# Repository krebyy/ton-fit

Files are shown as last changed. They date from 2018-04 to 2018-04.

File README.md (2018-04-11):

Ton-Fit V2.0
========

The Ton-Fit V2.0 Board is a development and prototyping platform based on the ARM Cortex-M4 32-bit microcontroller [STM32F405](http://www.st.com/en/microcontrollers/stm32f405rg.html).

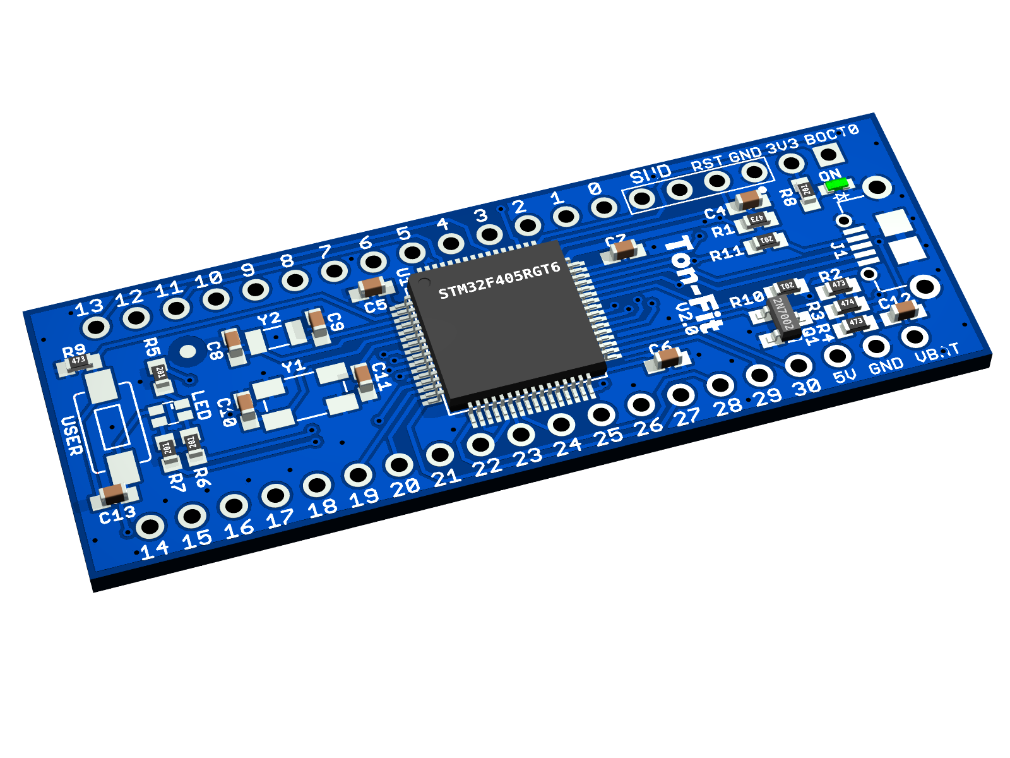
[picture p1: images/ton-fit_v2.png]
ton-fit_v2


# License

Copyright Kleber Lima da Silva 2018.

This documentation describes Open Hardware and is licensed under the CERN OHL v. 1.2.
You may redistribute and modify this documentation under the terms of the CERN OHL v.1.2. (http://ohwr.org/cernohl). This documentation is distributed WITHOUT ANY EXPRESS OR IMPLIED WARRANTY, INCLUDING OF MERCHANTABILITY, SATISFACTORY QUALITY AND FITNESS FOR A PARTICULAR PURPOSE. Please see the CERN OHL v.1.2 for applicable conditions.

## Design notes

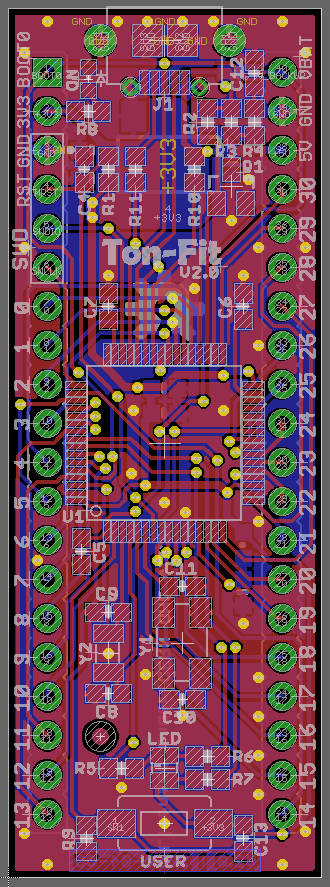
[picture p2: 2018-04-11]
images/ton-fit_v2_eagle.png

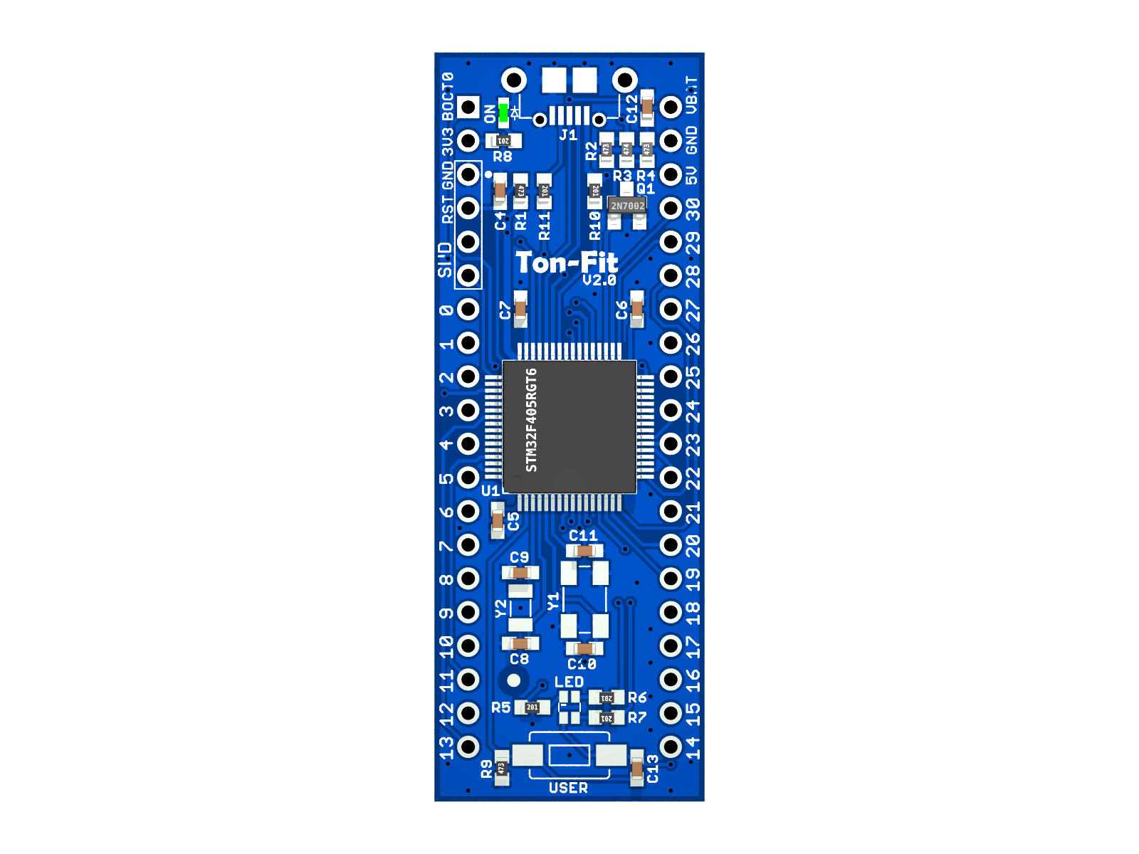
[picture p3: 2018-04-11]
images/ton-fit_v2_top.png

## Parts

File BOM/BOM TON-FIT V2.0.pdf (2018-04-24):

Idn | Reference Designator | Item Type | Item Package | Item Desc | Qty | MFG Name | MFG P/N | Notes
1 | C1, C14, C15 | CERAMIC-CAP | 0603 | CAP CER 1UF 6.3V X5R 0603 10% | 3 | YAGEO | CC0603KRX5R5BB105
2 | C2, C3, C4, C5, C13, C16 | CERAMIC-CAP | 0603 | CAP CER 0.1UF 16V X7R 0603 10% | 6 | YAGEO | CC0603KRX7R7BB104
3 | C6, C7, C12 | CERAMIC-CAP | 0603 | CAP CER 2.2UF 6.3V X5R 0603 10% | 3 | YAGEO | CC0603KRX5R5BB225
4 | C8, C9, C10, C11 | CERAMIC-CAP | 0603 | CAP CER 8.2PF 50V NP0 0603 | 4 | YAGEO | CC0603DRNPO9BN8R2
5 | J1 | USB-CONN | SMD-5 | CONNECTOR USB MICRO AB RECEPTACLE | 1 | MOLEX | 47589-0001
6 | J2 | CONNECTOR | PTH-40 | PIN HEADER 1X40, 2.54MM PITCH | 1 | HARWIN | M20-9994046
7 | L1 | FERRITE-CHIP | 0603 | FERRITE CHIP 120 OHM 500MA 0603 | 1 | TAIYO YUDEN | BK1608HS121-T
8 | LED | LED-RGB | 0606 | LED RGB 0606 | 1 | LITE-ON | LTST-C19HE1WT
9 | ON | LED | 0603 | LED GREEN 0603 | 1 | LITE-ON | LTST-C191KGKT
10 | Q1 | MOSFET | SOT-23-3 | MOSFET 2N7002 N-CHANNEL | 1 | ON SEMICONDUCTOR | 2N7002
11 | R1, R2, R4, R9 | RESISTOR-DISCRETE | 0603 | RES 0603 47K OHM 5% 1/10W | 4 | YAGEO | RC0603JR-0747KL
12 | R3 | RESISTOR-DISCRETE | 0603 | RES 0603 470K OHM 5% 1/10W | 1 | YAGEO | RC0603JR-07470KL
13 | R5, R6, R7, R8, R10, R11 | RESISTOR-DISCRETE | 0603 | RES 0603 200 OHM 5% 1/10W | 6 | YAGEO | RC0603JR-07200RL
14 | R12 | RESISTOR-DISCRETE | 0603 | JUMPER 0603 ZERO OHM | 1 | YAGEO | RC0603JR-070RL | NOT PLACED TO USE EXTERNAL BACKUP BATTERY
15 | U1 | IC | LQFP-64 | IC MCU STM32F405RGT6 | 1 | STMICROELECTRONICS | STM32F405RGT6
16 | U2 | IC | SOT-223-3 | IC LDO VOLTAGE REGULATOR 3.3V | 1 | DIODES INCORPORATED | AZ1117EH-3.3
17 | USER | TACTILE-SWITCH | SMD-4 | TACTILE SWITCH SPST-NO | 1 | TE CONNECTIVITY | FSMSM
18 | Y1 | CRYSTAL | SMD-4 | CRYSTAL ABM3B 8 MHZ | 1 | ABRACON | ABM3B-8.000MHZ-10-1UT
19 | Y2 | CRYSTAL | SMD-2 | CRYSTAL 32.768 KHZ | 1 | ECS | ECS-.327-7-34QCS-TR
Bill of Materials (BOM): TON-FIT V2.0

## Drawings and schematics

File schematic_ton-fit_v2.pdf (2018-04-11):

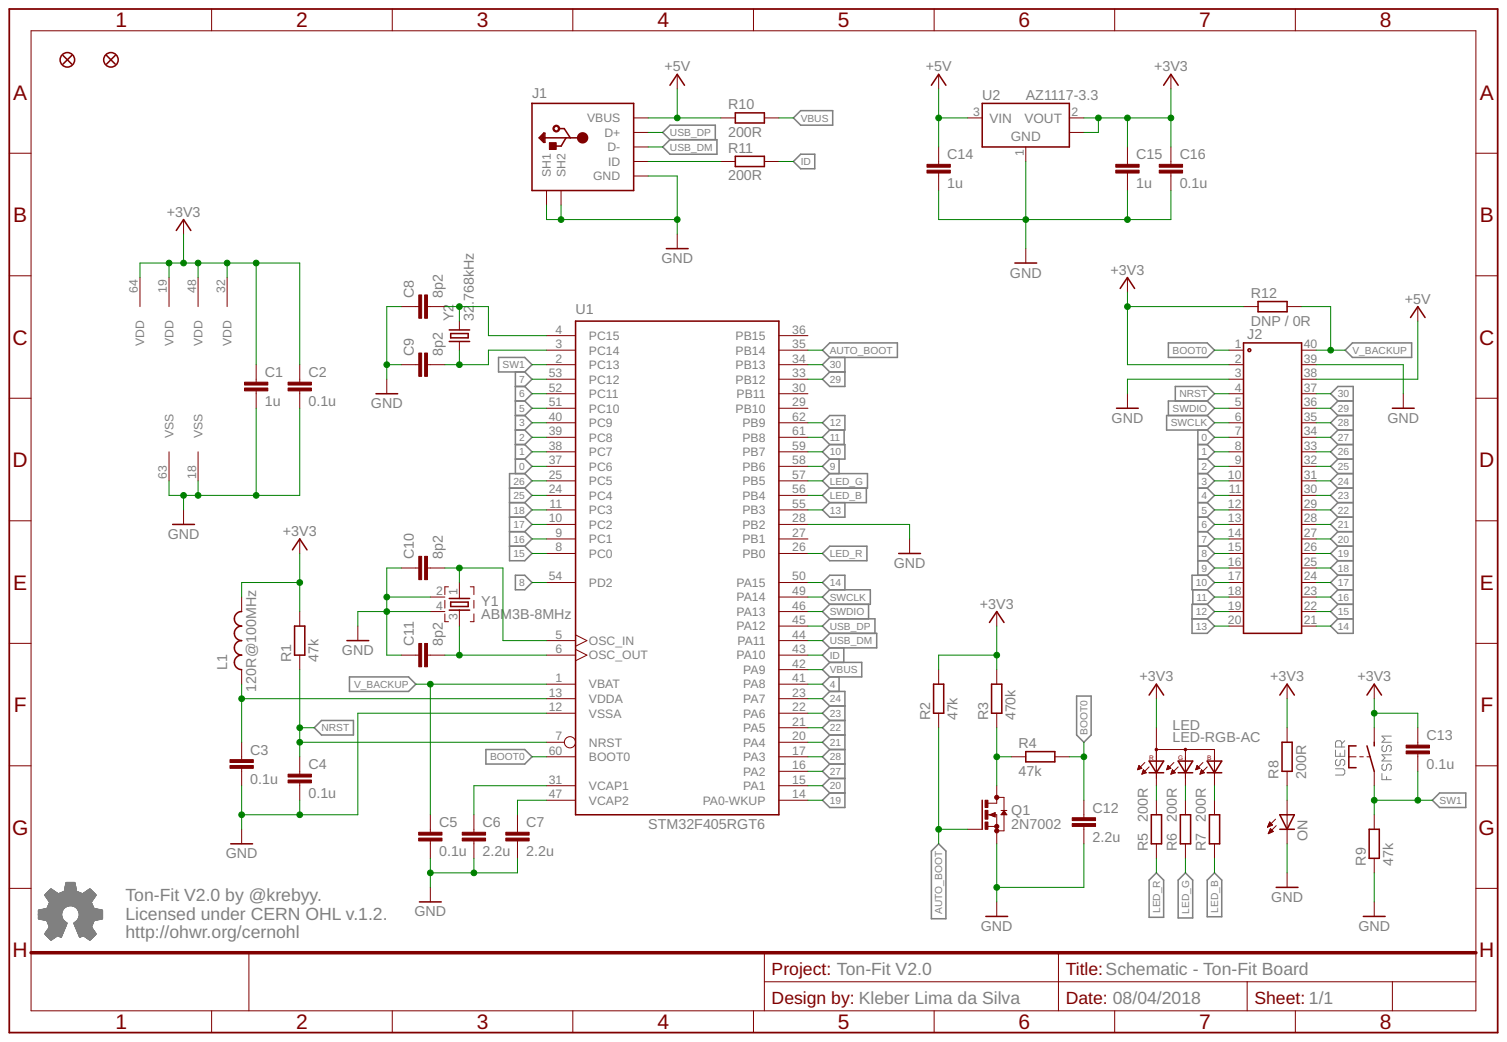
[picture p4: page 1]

Ton-Fit V2.0 by @krebyy. Licensed under CERN OHL v.1.2. http://ohwr.org/cernohl

Project: Ton-Fit V2.0 | Title: Schematic - Ton-Fit Board
Design by: Kleber Lima da Silva | Date: 08/04/2018 | Sheet: 1/1

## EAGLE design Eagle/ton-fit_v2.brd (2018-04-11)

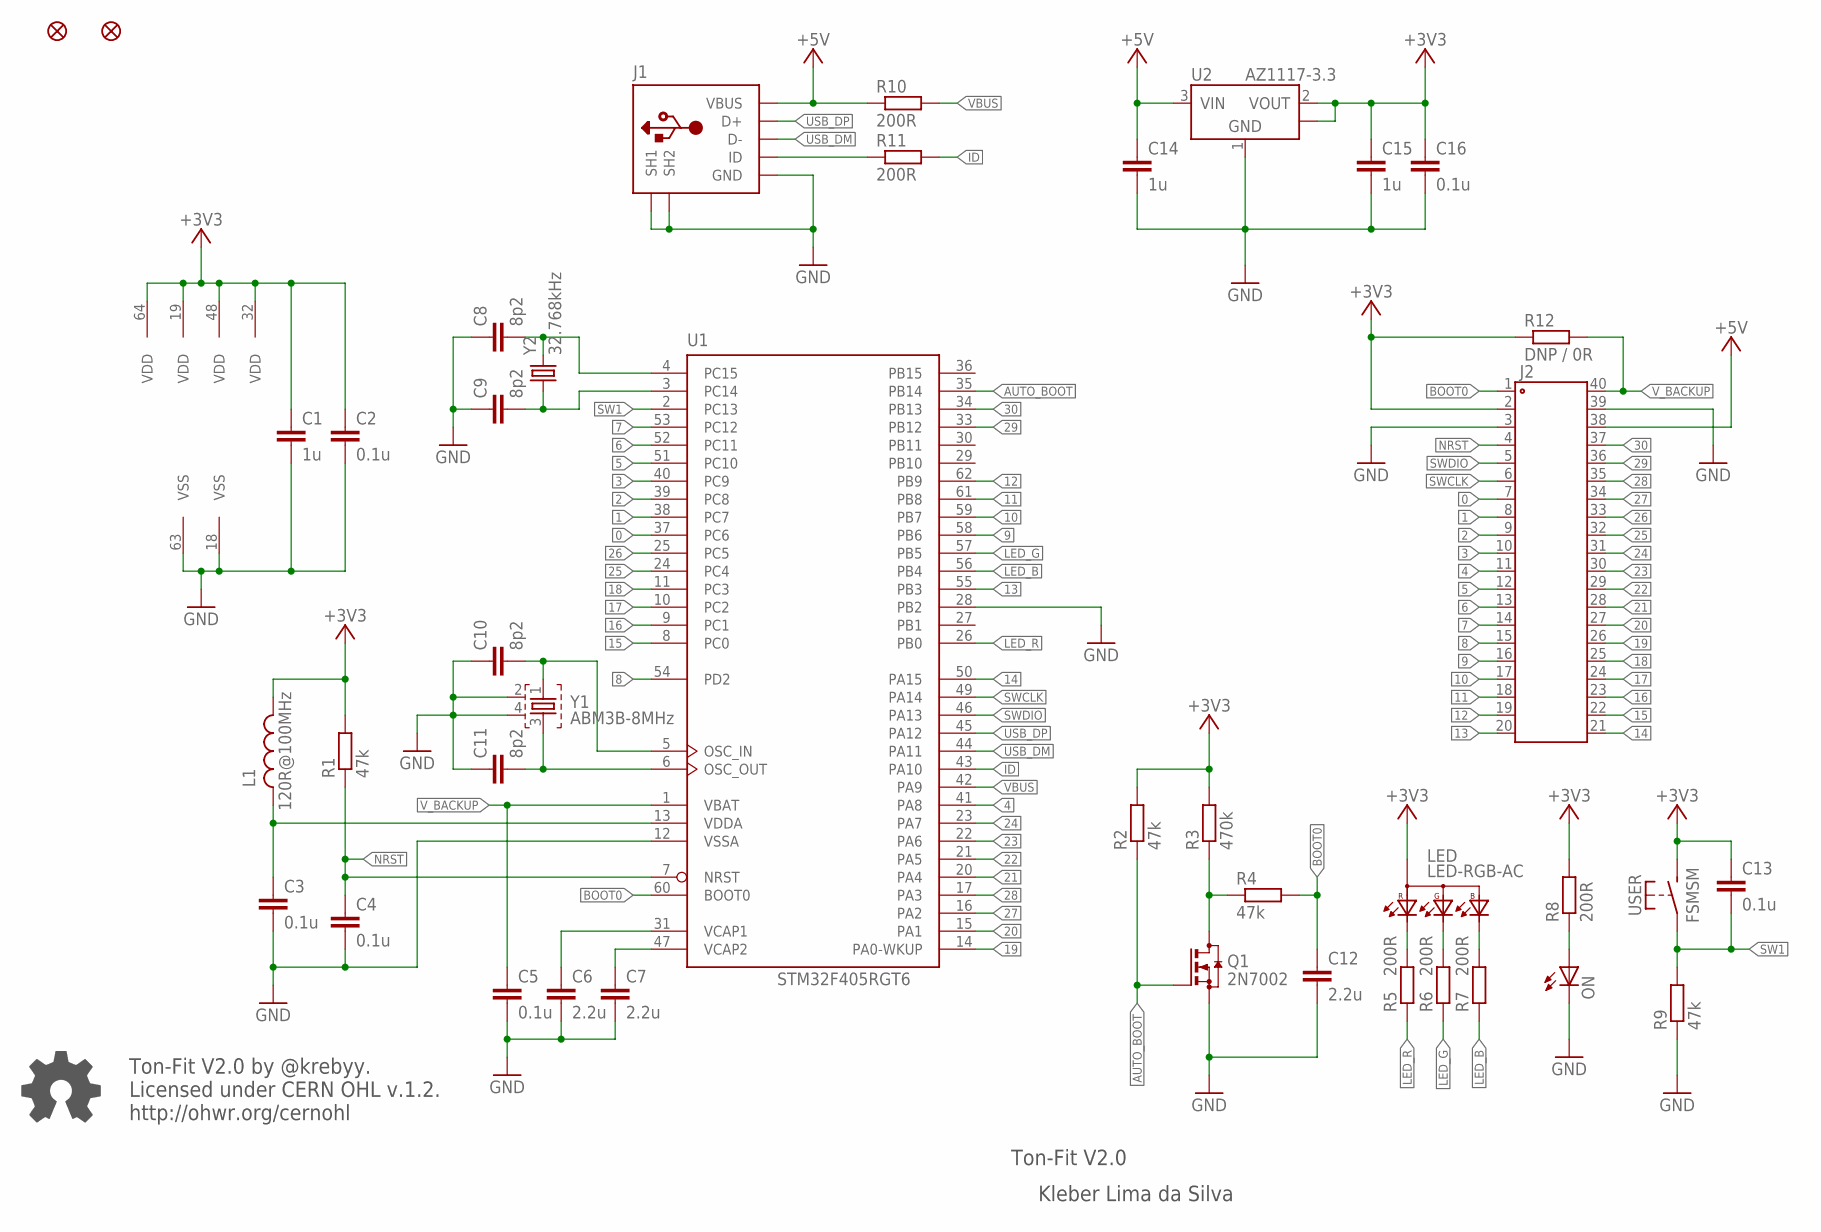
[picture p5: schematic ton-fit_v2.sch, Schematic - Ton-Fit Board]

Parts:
C1, C14, C15: 1u; C0603
C2, C3, C4, C5, C13, C16: 0.1u; C0603
C6, C7, C12: 2.2u; C0603
C8, C9, C10, C11: 8p2; C0603
FIDUCIAL1, FIDUCIAL2: FIDUCIAL; FIDUCIAL-1X2
J1: USBR; 0475890001
J2: DIL40
L1: 120R@100MHz; L0603
LED: LED-RGB-AC; 0606
ON: LEDCHIPLED_0603; CHIPLED_0603
Q1: 2N7002; SOT23
R1, R2, R4, R9: 47k; R0603
R3: 470k; R0603
R5, R6, R7, R8, R10, R11: 200R; R0603
R12: DNP / 0R; R0603
U1: STM32F405RGT6; LQFP64
U2: AZ1117-3.3; SOT223
USER: FSMSM
Y1: ABM3B-8MHz; ABM3B
Y2: 32.768kHz; 3.2X1.5

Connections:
0: J2.7, U1.37 (PC6)
1: J2.8, U1.38 (PC7)
2: J2.9, U1.39 (PC8)
3: J2.10, U1.40 (PC9)
4: J2.11, U1.41 (PA8)
5: J2.12, U1.51 (PC10)
6: J2.13, U1.52 (PC11)
7: J2.14, U1.53 (PC12)
8: J2.15, U1.54 (PD2)
9: J2.16, U1.58 (PB6)
10: J2.17, U1.59 (PB7)
11: J2.18, U1.61 (PB8)
12: J2.19, U1.62 (PB9)
13: J2.20, U1.55 (PB3)
14: J2.21, U1.50 (PA15)
15: J2.22, U1.8 (PC0)
16: J2.23, U1.9 (PC1)
17: J2.24, U1.10 (PC2)
18: J2.25, U1.11 (PC3)
19: J2.26, U1.14 (PA0-WKUP)
20: J2.27, U1.15 (PA1)
21: J2.28, U1.20 (PA4)
22: J2.29, U1.21 (PA5)
23: J2.30, U1.22 (PA6)
24: J2.31, U1.23 (PA7)
25: J2.32, U1.24 (PC4)
26: J2.33, U1.25 (PC5)
27: J2.34, U1.16 (PA2)
28: J2.35, U1.17 (PA3)
29: J2.36, U1.33 (PB12)
30: J2.37, U1.34 (PB13)
+3V3: C1.1, C2.1, C13.1, C15.1, C16.1, J2.2, L1.1, LED.4 (A), R1.2, R2.2, R3.2, R8.2, R12.1, U1.19 (VDD), U1.32 (VDD), U1.48 (VDD), U1.64 (VDD), U2.2 (VOUT), U2.4 (TAB), USER.2
+5V: C14.1, J1.1 (VBUS), J2.38, R10.1, U2.3 (VIN)
AUTO_BOOT: Q1.1 (G), R2.1, U1.35 (PB14)
BOOT0: C12.1, J2.1, R4.2, U1.60 (BOOT0)
GND: C1.2, C2.2, C3.2, C4.2, C5.2, C6.2, C7.2, C8.1, C9.1, C10.1, C11.1, C12.2, C14.2, C15.2, C16.2, J1.5 (GND), J1.SH1, J1.SH2 (SH1), J1.SH3 (SH2), J1.SH4 (SH2), J1.SH5 (SH1), J1.SH6 (SH2), J2.3, J2.39, ON.C, Q1.2 (S), R9.1, U1.12 (VSSA), U1.18 (VSS), U1.28 (PB2), U1.63 (VSS), U2.1 (GND), Y1.2, Y1.4
ID: R11.2, U1.43 (PA10)
LED_B: R7.1, U1.56 (PB4)
LED_G: R6.1, U1.57 (PB5)
LED_R: R5.1, U1.26 (PB0)
unnamed: C10.2, U1.5 (OSC_IN), Y1.1
unnamed: C11.2, U1.6 (OSC_OUT), Y1.3
unnamed: ON.A, R8.1
unnamed: LED.1 (KRED), R5.2
unnamed: C6.1, U1.31 (VCAP1)
unnamed: C7.1, U1.47 (VCAP2)
unnamed: LED.2 (KGREEN), R6.2
unnamed: LED.3 (KBLUE), R7.2
unnamed: C3.1, L1.2, U1.13 (VDDA)
unnamed: C8.2, U1.4 (PC15), Y2.2
unnamed: Q1.3 (D), R3.1, R4.1
unnamed: C9.2, U1.3 (PC14), Y2.1
NRST: C4.1, J2.4, R1.1, U1.7 (NRST)
SW1: C13.2, R9.2, U1.2 (PC13), USER.1
SWCLK: J2.6, U1.49 (PA14)
SWDIO: J2.5, U1.46 (PA13)
USB_DM: J1.2 (D-), U1.44 (PA11)
USB_DP: J1.3 (D+), U1.45 (PA12)
USB_ID: J1.4 (ID), R11.1
VBUS: R10.2, U1.42 (PA9)
V_BACKUP: C5.1, J2.40, R12.2, U1.1 (VBAT)

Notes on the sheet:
Ton-Fit V2.0 by @krebyy. Licensed under CERN OHL v.1.2. http://ohwr.org/cernohl
Ton-Fit V2.0
Kleber Lima da Silva

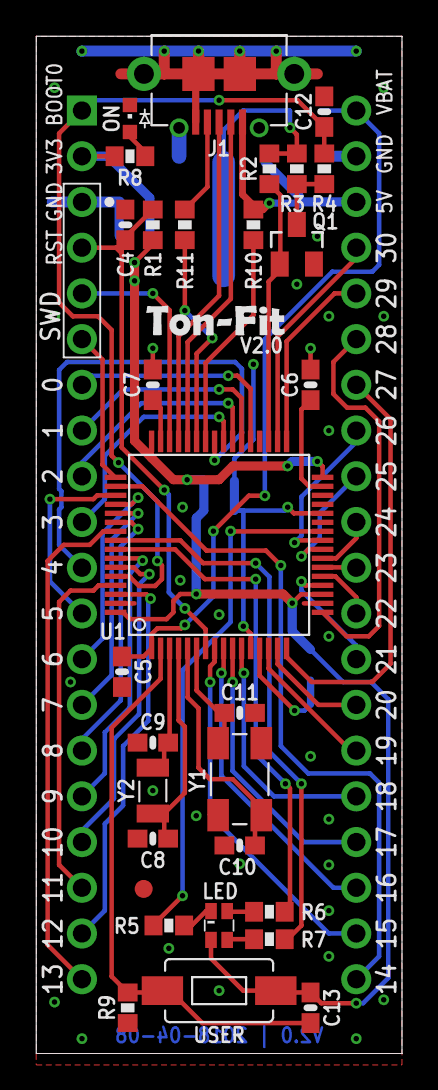
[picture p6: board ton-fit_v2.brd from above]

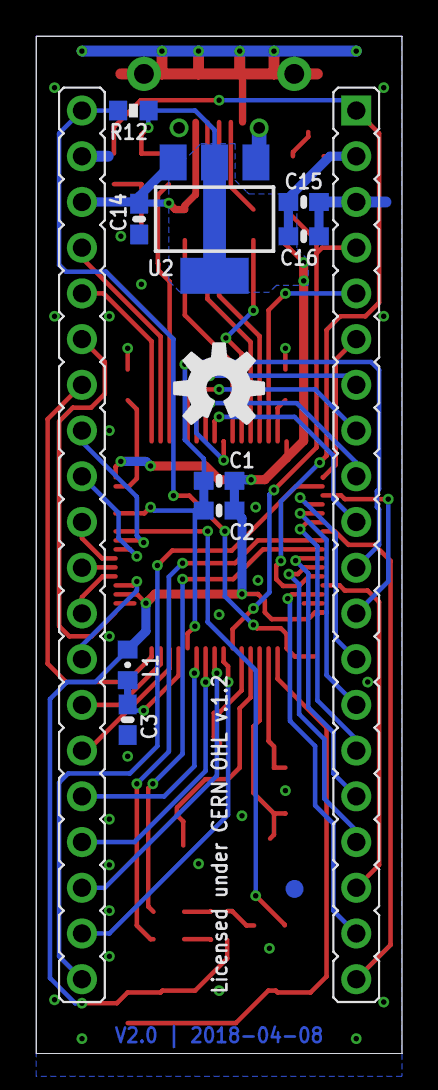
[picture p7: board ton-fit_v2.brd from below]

Board: 2 copper layers, 20.3 x 56.5 mm, 42 parts (11 on the bottom side), 61 nets.

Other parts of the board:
U$1: OSHW-LOGO-M

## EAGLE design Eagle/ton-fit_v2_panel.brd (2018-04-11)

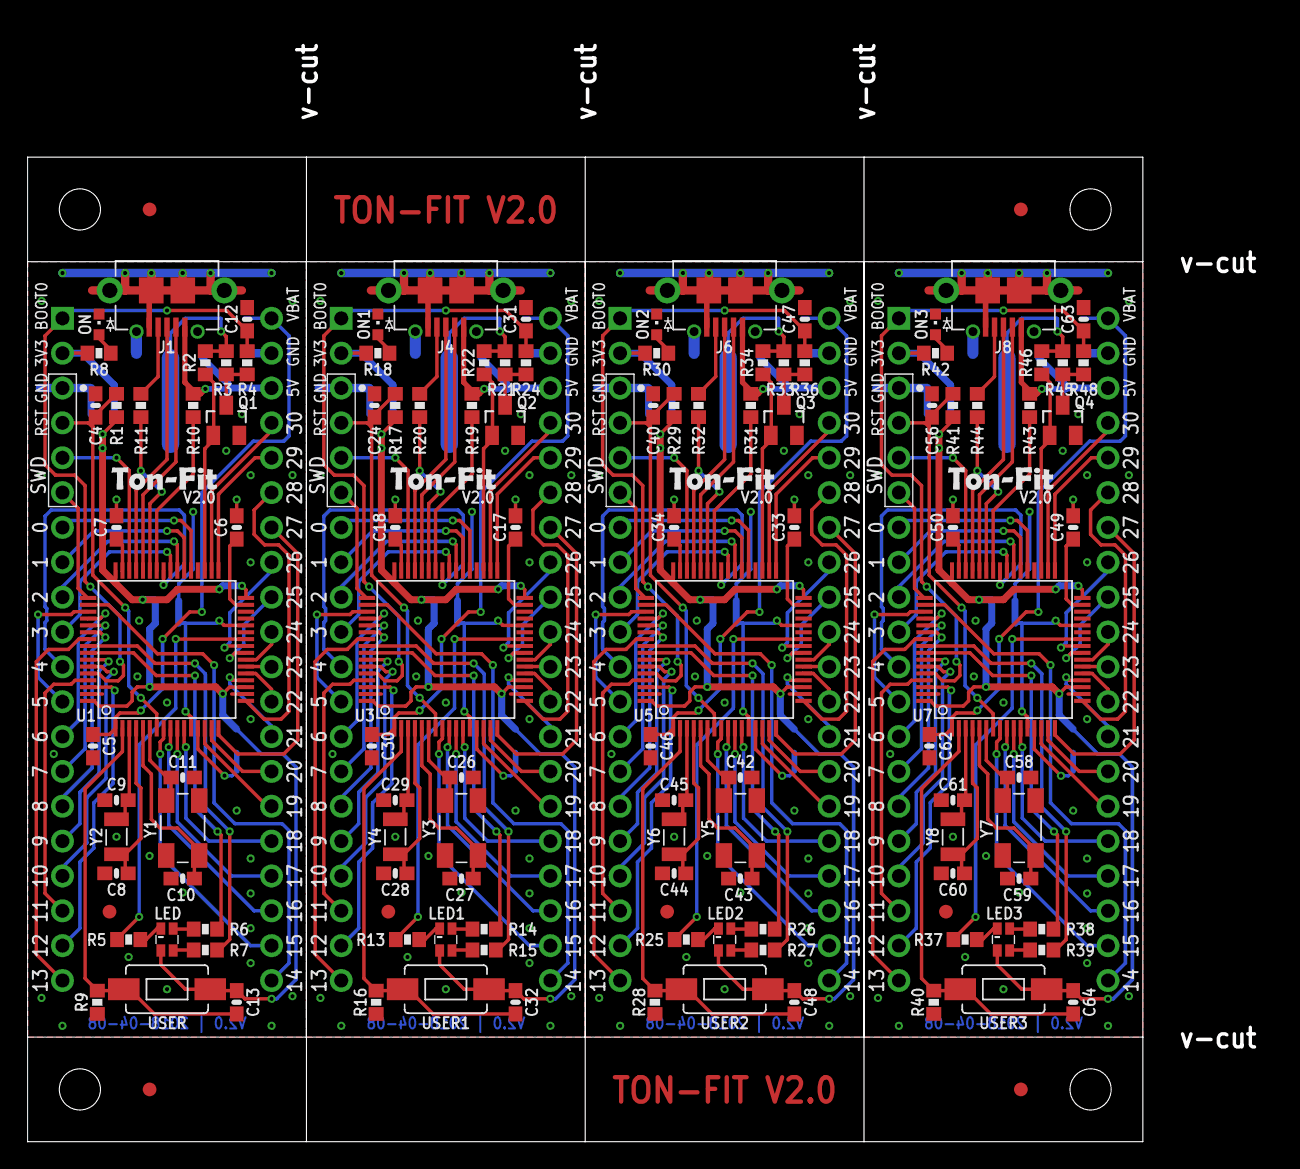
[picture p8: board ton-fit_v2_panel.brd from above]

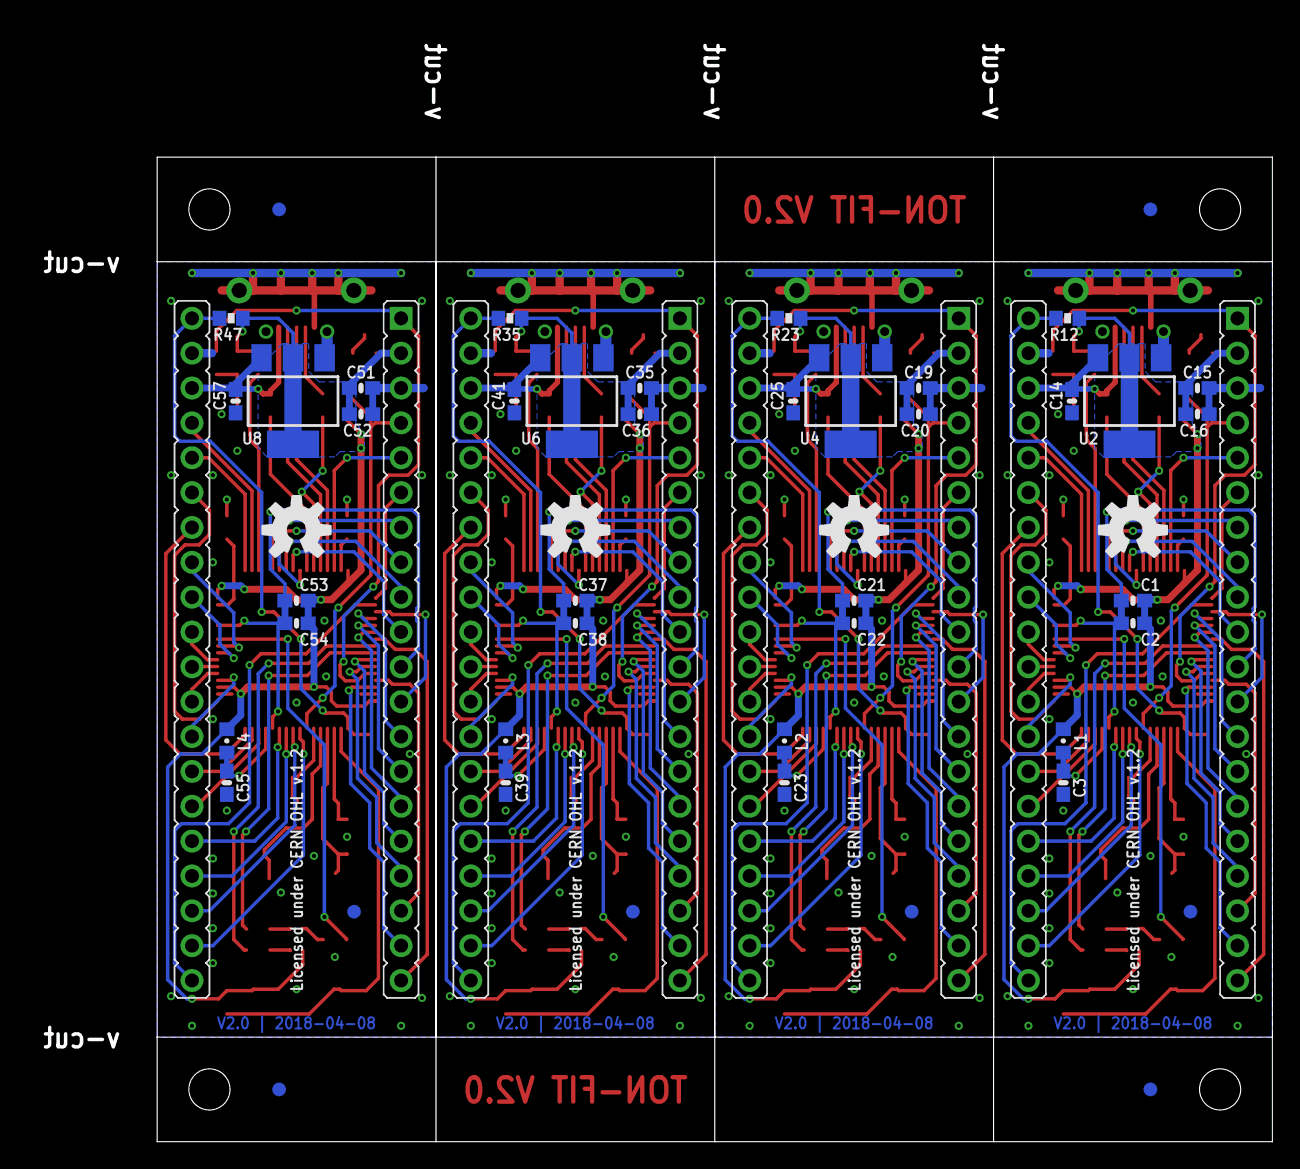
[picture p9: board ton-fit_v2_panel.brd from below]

Board: 2 copper layers, 81.3 x 71.8 mm, 176 parts (48 on the bottom side), 244 nets.

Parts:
C1, C14, C15, C19, C21, C25, C35, C37, C41, C51, C53, C57: 1u; C0603
C2, C3, C4, C5, C13, C16, C20, C22, C23, C24, C30, C32, C36, C38, C39, C40, C46, C48, C52, C54, C55, C56, C62, C64: 0.1u; C0603
C6, C7, C12, C17, C18, C31, C33, C34, C47, C49, C50, C63: 2.2u; C0603
C8, C9, C10, C11, C26, C27, C28, C29, C42, C43, C44, C45, C58, C59, C60, C61: 8p2; C0603
E$1, E$2, E$3, E$4, E$5, E$6, E$7, E$8: FIDUCIAL-1X2
FIDUCIAL1, FIDUCIAL2, FIDUCIAL3, FIDUCIAL4, FIDUCIAL5, FIDUCIAL6, FIDUCIAL7, FIDUCIAL8: FIDUCIAL; FIDUCIAL-1X2
J1, J4, J6, J8: 0475890001
J2, J3, J5, J7: DIL40
L1, L2, L3, L4: 120R@100MHz; L0603
LED, LED1, LED2, LED3: LED-RGB-AC; 0606
ON, ON1, ON2, ON3: CHIPLED_0603
Q1, Q2, Q3, Q4: 2N7002; SOT23
R1, R2, R4, R9, R16, R17, R22, R24, R28, R29, R34, R36, R40, R41, R46, R48: 47k; R0603
R3, R21, R33, R45: 470k; R0603
R5, R6, R7, R8, R10, R11, R13, R14, R15, R18, R19, R20, R25, R26, R27, R30, R31, R32, R37, R38, R39, R42, R43, R44: 200R; R0603
R12, R23, R35, R47: DNP / 0R; R0603
U1, U3, U5, U7: STM32F405RGT6; LQFP64
U2, U4, U6, U8: AZ1117-3.3; SOT223
U$1, U$2, U$3, U$4: OSHW-LOGO-M
USER, USER1, USER2, USER3: FSMSM
Y1, Y3, Y5, Y7: ABM3B-8MHz; ABM3B
Y2, Y4, Y6, Y8: 32.768kHz; 3.2X1.5

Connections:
0: J2.7, U1.37
1: J2.8, U1.38
2: J2.9, U1.39
3: J2.10, U1.40
4: J2.11, U1.41
5: J2.12, U1.51
6: J2.13, U1.52
7: J2.14, U1.53
8: J2.15, U1.54
9: J2.16, U1.58
10: J2.17, U1.59
11: J2.18, U1.61
12: J2.19, U1.62
13: J2.20, U1.55
14: J2.21, U1.50
15: J2.22, U1.8
16: J2.23, U1.9
17: J2.24, U1.10
18: J2.25, U1.11
19: J2.26, U1.14
20: J2.27, U1.15
21: J2.28, U1.20
22: J2.29, U1.21
23: J2.30, U1.22
24: J2.31, U1.23
25: J2.32, U1.24
26: J2.33, U1.25
27: J2.34, U1.16
28: J2.35, U1.17
29: J2.36, U1.33
30: J2.37, U1.34
31: J3.12, U3.51
32: J3.17, U3.59
33: J3.16, U3.58
34: J3.15, U3.54
35: J3.14, U3.53
36: J3.13, U3.52
37: J3.8, U3.38
38: J3.7, U3.37
39: J3.36, U3.33
40: J3.35, U3.17
41: J3.34, U3.16
42: J3.33, U3.25
43: J3.32, U3.24
44: J3.31, U3.23
45: J3.30, U3.22
46: J3.29, U3.21
47: J3.28, U3.20
48: J3.27, U3.15
49: J3.26, U3.14
50: J3.25, U3.11
51: J3.24, U3.10
52: J3.9, U3.39
53: J3.10, U3.40
54: J3.11, U3.41
55: J3.18, U3.61
56: J3.19, U3.62
57: J3.20, U3.55
58: J3.21, U3.50
59: J3.22, U3.8
60: J3.23, U3.9
61: J3.37, U3.34
62: J5.12, U5.51
63: J5.17, U5.59
64: J5.16, U5.58
65: J5.15, U5.54
66: J5.14, U5.53
67: J5.13, U5.52
68: J5.8, U5.38
69: J5.7, U5.37
70: J5.36, U5.33
71: J5.35, U5.17
72: J5.34, U5.16
73: J5.33, U5.25
74: J5.32, U5.24
75: J5.31, U5.23
76: J5.30, U5.22
77: J5.29, U5.21
78: J5.28, U5.20
79: J5.27, U5.15
80: J5.26, U5.14
81: J5.25, U5.11
82: J5.24, U5.10
83: J5.9, U5.39
84: J5.10, U5.40
85: J5.11, U5.41
86: J5.18, U5.61
87: J5.19, U5.62
88: J5.20, U5.55
89: J5.21, U5.50
90: J5.22, U5.8
91: J5.23, U5.9
92: J5.37, U5.34
93: J7.12, U7.51
94: J7.17, U7.59
95: J7.16, U7.58
96: J7.15, U7.54
97: J7.14, U7.53
98: J7.13, U7.52
99: J7.8, U7.38
100: J7.7, U7.37
101: J7.36, U7.33
102: J7.35, U7.17
103: J7.34, U7.16
104: J7.33, U7.25
105: J7.32, U7.24
106: J7.31, U7.23
107: J7.30, U7.22
108: J7.29, U7.21
109: J7.28, U7.20
110: J7.27, U7.15
111: J7.26, U7.14
112: J7.25, U7.11
113: J7.24, U7.10
114: J7.9, U7.39
115: J7.10, U7.40
116: J7.11, U7.41
117: J7.18, U7.61
118: J7.19, U7.62
119: J7.20, U7.55
120: J7.21, U7.50
121: J7.22, U7.8
122: J7.23, U7.9
123: J7.37, U7.34
+3V1: C19.1, C20.1, C21.1, C22.1, C32.1, J3.2, L2.1, LED1.4, R17.2, R18.2, R21.2, R22.2, R23.1, U3.19, U3.32, U3.48, U3.64, U4.2, U4.4, USER1.2
+3V2: C35.1, C36.1, C37.1, C38.1, C48.1, J5.2, L3.1, LED2.4, R29.2, R30.2, R33.2, R34.2, R35.1, U5.19, U5.32, U5.48, U5.64, U6.2, U6.4, USER2.2
+3V3: C1.1, C2.1, C13.1, C15.1, C16.1, J2.2, L1.1, LED.4, R1.2, R2.2, R3.2, R8.2, R12.1, U1.19, U1.32, U1.48, U1.64, U2.2, U2.4, USER.2
+3V4: C51.1, C52.1, C53.1, C54.1, C64.1, J7.2, L4.1, LED3.4, R41.2, R42.2, R45.2, R46.2, R47.1, U7.19, U7.32, U7.48, U7.64, U8.2, U8.4, USER3.2
+5V: C14.1, J1.1, J2.38, R10.1, U2.3
+5V1: C25.1, J3.38, J4.1, R19.1, U4.3
+5V2: C41.1, J5.38, J6.1, R31.1, U6.3
+5V3: C57.1, J7.38, J8.1, R43.1, U8.3
AUTO_BOOT: Q1.1, R2.1, U1.35
AUTO_BOOT1: Q2.1, R22.1, U3.35
AUTO_BOOT2: Q3.1, R34.1, U5.35
AUTO_BOOT3: Q4.1, R46.1, U7.35
BOOT0: C12.1, J2.1, R4.2, U1.60
BOOT1: C31.1, J3.1, R24.2, U3.60
BOOT2: C47.1, J5.1, R36.2, U5.60
BOOT3: C63.1, J7.1, R48.2, U7.60
GND: C1.2, C2.2, C3.2, C4.2, C5.2, C6.2, C7.2, C8.1, C9.1, C10.1, C11.1, C12.2, C14.2, C15.2, C16.2, J1.5, J1.SH1, J1.SH2, J1.SH3, J1.SH4, J1.SH5, J1.SH6, J2.3, J2.39, ON.C, Q1.2, R9.1, U1.12, U1.18, U1.28, U1.63, U2.1, Y1.2, Y1.4
GND1: C17.2, C18.2, C19.2, C20.2, C21.2, C22.2, C23.2, C24.2, C25.2, C26.1, C27.1, C28.1, C29.1, C30.2, C31.2, J3.3, J3.39, J4.5, J4.SH1, J4.SH2, J4.SH3, J4.SH4, J4.SH5, J4.SH6, ON1.C, Q2.2, R16.1, U3.12, U3.18, U3.28, U3.63, U4.1, Y3.2, Y3.4
GND2: C33.2, C34.2, C35.2, C36.2, C37.2, C38.2, C39.2, C40.2, C41.2, C42.1, C43.1, C44.1, C45.1, C46.2, C47.2, J5.3, J5.39, J6.5, J6.SH1, J6.SH2, J6.SH3, J6.SH4, J6.SH5, J6.SH6, ON2.C, Q3.2, R28.1, U5.12, U5.18, U5.28, U5.63, U6.1, Y5.2, Y5.4
GND3: C49.2, C50.2, C51.2, C52.2, C53.2, C54.2, C55.2, C56.2, C57.2, C58.1, C59.1, C60.1, C61.1, C62.2, C63.2, J7.3, J7.39, J8.5, J8.SH1, J8.SH2, J8.SH3, J8.SH4, J8.SH5, J8.SH6, ON3.C, Q4.2, R40.1, U7.12, U7.18, U7.28, U7.63, U8.1, Y7.2, Y7.4
ID: R11.2, U1.43
ID1: R20.2, U3.43
ID2: R32.2, U5.43
ID3: R44.2, U7.43
LED_B: R7.1, U1.56
LED_B1: R15.1, U3.56
LED_B2: R27.1, U5.56
LED_B3: R39.1, U7.56
LED_G: R6.1, U1.57
LED_G1: R14.1, U3.57
LED_G2: R26.1, U5.57
LED_G3: R38.1, U7.57
LED_R: R5.1, U1.26
LED_R1: R13.1, U3.26
LED_R2: R25.1, U5.26
LED_R3: R37.1, U7.26
unnamed: C10.2, U1.5, Y1.1
unnamed: C11.2, U1.6, Y1.3
unnamed: ON.A, R8.1
unnamed: LED.1, R5.2
unnamed: C6.1, U1.31
unnamed: C7.1, U1.47
unnamed: LED.2, R6.2
unnamed: LED.3, R7.2
unnamed: C3.1, L1.2, U1.13
unnamed: C17.1, U3.31
unnamed: C8.2, U1.4, Y2.2
unnamed: Q1.3, R3.1, R4.1
unnamed: C18.1, U3.47
unnamed: LED1.1, R13.2
unnamed: C9.2, U1.3, Y2.1
unnamed: LED1.2, R14.2
unnamed: LED1.3, R15.2
unnamed: C23.1, L2.2, U3.13
unnamed: ON1.A, R18.1
unnamed: C27.2, U3.5, Y3.1
unnamed: C26.2, U3.6, Y3.3
unnamed: C28.2, U3.4, Y4.2
unnamed: C29.2, U3.3, Y4.1
unnamed: Q2.3, R21.1, R24.1
unnamed: C33.1, U5.31
unnamed: C34.1, U5.47
unnamed: LED2.1, R25.2
unnamed: LED2.2, R26.2
unnamed: LED2.3, R27.2
unnamed: C39.1, L3.2, U5.13
unnamed: ON2.A, R30.1
unnamed: C43.2, U5.5, Y5.1
unnamed: C42.2, U5.6, Y5.3
unnamed: C44.2, U5.4, Y6.2
unnamed: C45.2, U5.3, Y6.1
unnamed: Q3.3, R33.1, R36.1
unnamed: C49.1, U7.31
unnamed: C50.1, U7.47
unnamed: LED3.1, R37.2
unnamed: LED3.2, R38.2
unnamed: LED3.3, R39.2
unnamed: C55.1, L4.2, U7.13
unnamed: ON3.A, R42.1
unnamed: C59.2, U7.5, Y7.1
unnamed: C58.2, U7.6, Y7.3
unnamed: C60.2, U7.4, Y8.2
unnamed: C61.2, U7.3, Y8.1
unnamed: Q4.3, R45.1, R48.1
NRST: C4.1, J2.4, R1.1, U1.7
NRST1: C24.1, J3.4, R17.1, U3.7
NRST2: C40.1, J5.4, R29.1, U5.7
NRST3: C56.1, J7.4, R41.1, U7.7
SW1: C13.2, R9.2, U1.2, USER.1
SW2: C32.2, R16.2, U3.2, USER1.1
SW3: C48.2, R28.2, U5.2, USER2.1
SW4: C64.2, R40.2, U7.2, USER3.1
SWCLK: J2.6, U1.49
SWCLK1: J3.6, U3.49
SWCLK2: J5.6, U5.49
SWCLK3: J7.6, U7.49
SWDIO: J2.5, U1.46
SWDIO1: J3.5, U3.46
SWDIO2: J5.5, U5.46
SWDIO3: J7.5, U7.46
USB_DM: J1.2, U1.44
USB_DM1: J4.2, U3.44
USB_DM2: J6.2, U5.44
USB_DM3: J8.2, U7.44
USB_DP: J1.3, U1.45
USB_DP1: J4.3, U3.45
USB_DP2: J6.3, U5.45
USB_DP3: J8.3, U7.45
USB_ID: J1.4, R11.1
USB_ID1: J4.4, R20.1
USB_ID2: J6.4, R32.1
USB_ID3: J8.4, R44.1
VBUS: R10.2, U1.42
VBUS1: R19.2, U3.42
VBUS2: R31.2, U5.42
VBUS3: R43.2, U7.42
V_BACKUP: C5.1, J2.40, R12.2, U1.1
V_BACKUP1: C30.1, J3.40, R23.2, U3.1
V_BACKUP2: C46.1, J5.40, R35.2, U5.1
V_BACKUP3: C62.1, J7.40, R47.2, U7.1

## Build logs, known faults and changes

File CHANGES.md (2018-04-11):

Here we are compiling a community changelog.

If you come up with a modification of our designs, please share it with the community, log your changes below, and upload the files to our GitHub repository.

# Format

**Your name**  
*Date*  
Description of modification  

# Example

* older entry

* **Kleber Lima da Silva**   
*12/31/2032*  
I used the original board design (electronics), but changed the microcontroller. I created a pull request on GitHub with the modified files.

* newer entry

# Changelog

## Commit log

2018-04-11 First commit - Board V2.0
    [ton-fit_v2.brd, ton-fit_v2.sch, ton-fit_v2_panel.brd]
2018-04-11 Rename schematic pdf
2018-04-24 Fix BOM - U2 part number

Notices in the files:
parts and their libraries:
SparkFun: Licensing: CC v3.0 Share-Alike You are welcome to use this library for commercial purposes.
